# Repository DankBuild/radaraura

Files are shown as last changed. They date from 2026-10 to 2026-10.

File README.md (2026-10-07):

# RadarAura

A desk air-quality monitor: a 4.3" ESP32-P4 touch display plus a Sensirion SEN66
sensor in a 3D-printed case. It shows CO2, particulate matter (PM1/2.5/4/10), VOC
and NOx indices, temperature and humidity, with a one-hour CO2 trend and a plain
"what should I do" line.

**Build guide with wiring pictures: <https://radaraura.com/build/>**

<p>
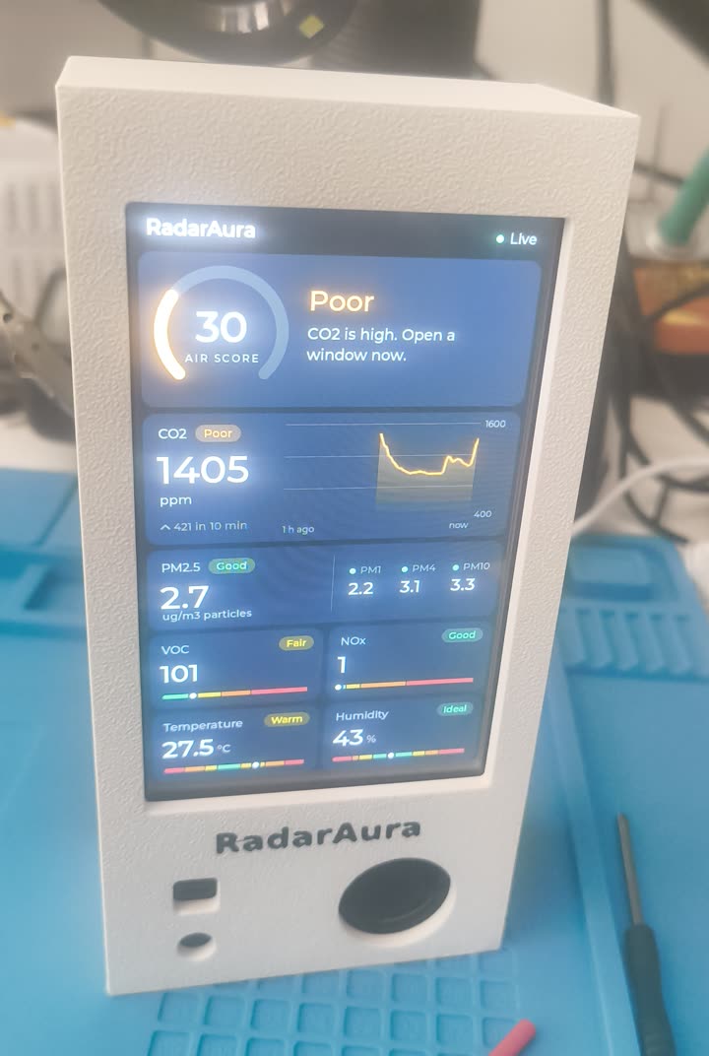
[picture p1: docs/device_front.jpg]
The finished RadarAura monitor in its white printed case, the screen showing an air score of 30 and CO2 at 1405 ppm
  
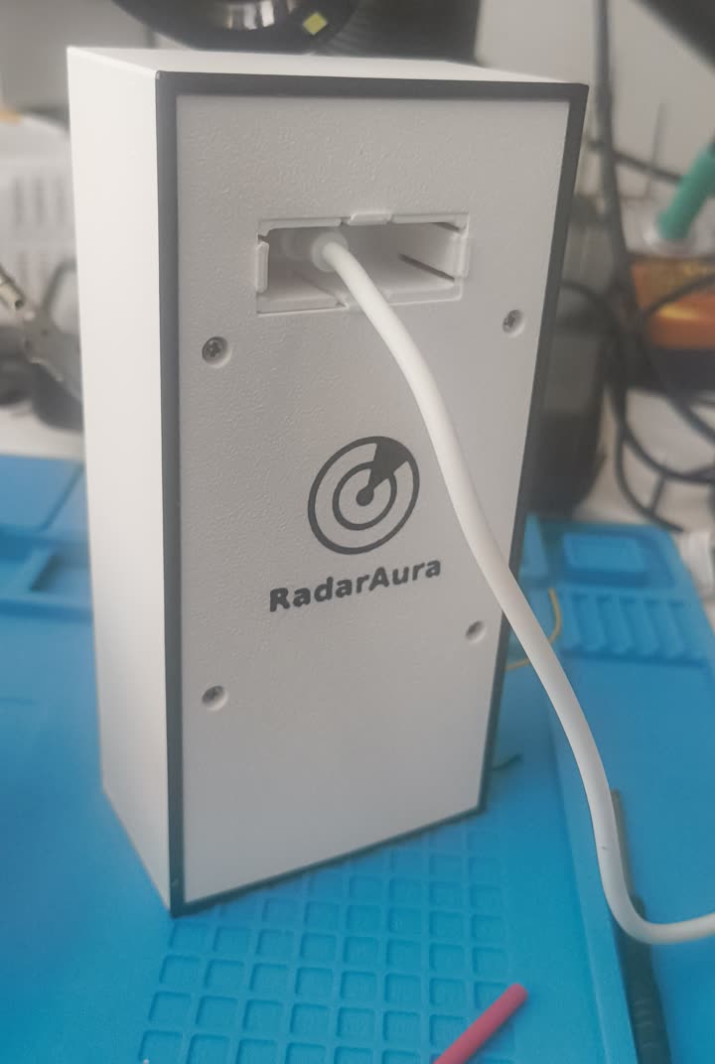
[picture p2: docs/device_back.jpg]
The back of the case with the radar mark, the RadarAura name and the USB-C cable
  
</p>

<p>
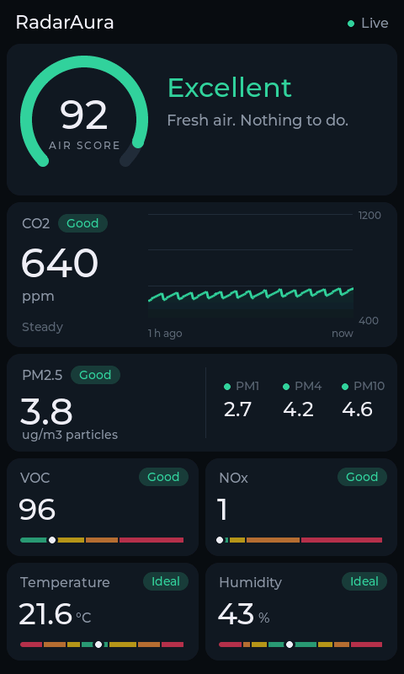
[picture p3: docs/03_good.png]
Dashboard with fresh air
  
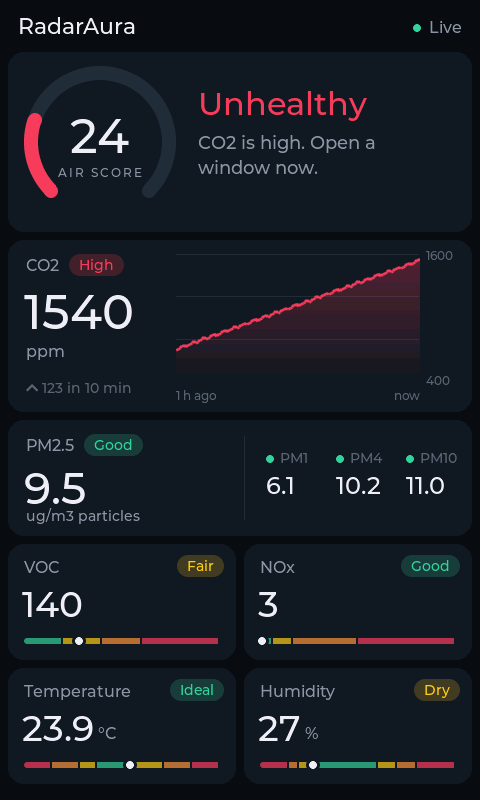
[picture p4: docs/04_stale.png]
Dashboard with high CO2
  
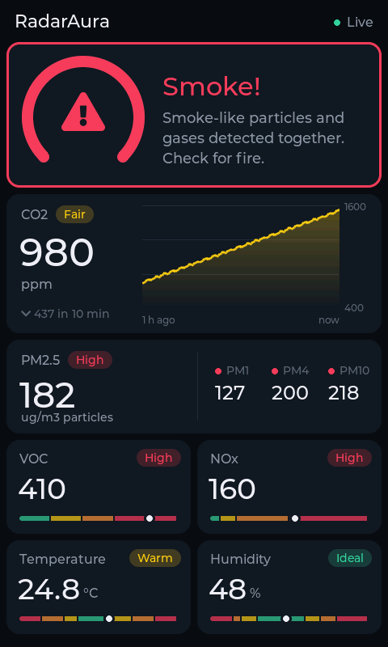
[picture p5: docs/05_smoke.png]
Smoke warning
  
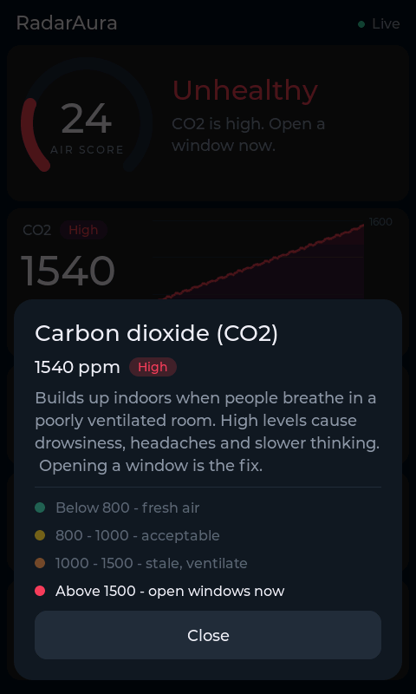
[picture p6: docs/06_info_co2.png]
CO2 explanation sheet
  
</p>

**Private by design:** no WiFi, no Bluetooth, no microphone. The board's ESP32-C6
radio chip is held in reset from the first instruction and no radio stack is
compiled in; the microphone is never switched on. Everything stays on the device.

## What you need

| # | Get this | Notes |
|---|---|---|
| 1 | **Guition JC4880P443C-I-W**, the bare board | ESP32-P4 with a 4.3" 480x800 touch screen (ST7701). Buy the version **without** the factory case (the one in its own plastic shell is usually listed with a "-Y" at the end); the RadarAura case is made for the bare board |
| 2 | **Sensirion SEN66** | PM, RH/T, VOC, NOx and CO2 in one module. Not the SEN63C, SEN65 or SEN68 |
| 3 | **SEN66 cable**: 6-pin, 1.25 mm pitch, JST GH type | Often sold separately, so check your order includes it. Wire colours don't matter |
| 4 | **A 3D printer, or someone to print for you** | Three parts in PETG, see [`case/`](case/README.md): one-colour or two-colour. A friend, makerspace, library or print service can print the STLs |

Tools: a soldering iron, heat-shrink, a USB-C cable with a USB power supply, and a
computer with ESP-IDF 5.3 to flash the firmware once. Optional: 4x M2 pan-head
screws (the case plugs tightly together and holds without them) and a second
filament colour for the name and radar mark. No resistors or other extra parts
are needed.

**Skill:** basic soldering. The four wires are soldered to the header pins. Female
jumper wires pushed onto the pins can work for a quick test, but they can slip or
lose contact when the case is closed ("Sensor offline"), and one slipping onto the
5 V pin next to pin 1 can damage the SEN66. Solder them for a device you keep.

**Wiring:** only 4 of the SEN66's 6 wires are needed (pins 5 and 6 repeat GND
and 3.3 V inside the sensor). They go to the board's 2x13 header, on the row
nearest the USB-C ports:

| SEN66 wire | Signal | Header pin |
|---|---|---|
| 1 (end of the plug farthest from the round outlet) | 3.3 V | 1 |
| 2 | GND | 5 |
| 3 | SDA (GPIO7) | 23 |
| 4 | SCL (GPIO8) | 25 |

Ignore the wire colours: these clip-in cables are not colour-coded consistently,
so red is not always 3.3 V and black is not always GND. Count by position from
wire 1.

Slide heat-shrink onto each wire before soldering, then shrink it over the joint:
no bare metal may touch a neighbouring pin (23 and 25 sit side by side, and the
5 V pins are next to pin 1).

The first two pins of the other row carry **5 V**: don't use them. I2C address
0x6B; the board already has the pull-ups. Pictures: <https://radaraura.com/build/#wiring>.

## Firmware

Requires [ESP-IDF](https://docs.espressif.com/projects/esp-idf/) 5.3 (tested with 5.3.5).

```sh
cd firmware
idf.py build
idf.py -p /dev/ttyACM0 flash monitor
```

RadarAura has no speaker: warnings, including the smoke warning, are shown on
the screen. The firmware still contains alert-sound code (settings at the top of
`firmware/main/main.c`, spoken alerts via `tools/generate_tts.py`), but the
standard build has nothing to play them on.

> The smoke warning is a convenience, **not a certified smoke detector**. Use a
> real smoke alarm for life safety.

### UI screenshots without hardware

`tools/ui_sim/build.sh` renders the dashboard on a PC to PNGs (run a firmware
build first; it reuses LVGL from `firmware/managed_components`).

## Case

See [`case/README.md`](case/README.md).

## Licence

Free to build and change for yourself, with the RadarAura name kept on the case
and the screen; selling requires permission. Everything is under the
[RadarAura Build Licence](LICENSE.md); the name rules are summed up in
[TRADEMARK.md](TRADEMARK.md).

Copyright (c) 2026 DankBuild.

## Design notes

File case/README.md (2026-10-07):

# Case

Printed parts, generated by `atmo4.py`. The STLs are already laid flat in print
orientation. Outside size about 72 x 149 x 42 mm. The SEN66 sits in its own
chamber below the screen with its air ports against the front openings.

## Choose how to print

The RadarAura name on the front and the radar mark on the back are part of the
case in both options (see [TRADEMARK.md](../TRADEMARK.md)).

### Option A: one colour (any printer)

Print these three parts. The name and the radar mark come out recessed 0.6 mm.

| File | Part | Lay it |
|---|---|---|
| `stl/v4_front_body.stl` | Front shell: screen window, sensor chamber in the chin, air openings, recessed name | screen face down |
| `stl/v4_rear_cover.stl` | Rear cover: screw posts, snap hooks, USB window, recessed radar mark | back down |
| `stl/v4_usb_insert.stl` | USB-C insert that clicks into the cover's window | floor down |

The recessed name is subtle in one colour. To make it readable, rub a little
acrylic paint (or a paint-marker line) into the letters and wipe the surface
clean before it dries.

### Option B: two colours (name and mark in a second colour)

The same three parts, plus two inlays that fill the recesses flush:

| File | Part |
|---|---|
| `stl/v4_front_body_name.stl` | The name, fills the recess in the front shell |
| `stl/v4_rear_cover_icon.stl` | The radar mark and name, fills the recess in the rear cover |

**Any printer:** everything above is in `stl/`, and STL files work in every
slicer (PrusaSlicer, Cura, OrcaSlicer, Bambu Studio and others).

**Multi-material printer (AMS, MMU, tool changer), from the STLs:**

1. Load the body and its inlay as **one object with two parts**:
   `v4_front_body.stl` + `v4_front_body_name.stl` for the front,
   `v4_rear_cover.stl` + `v4_rear_cover_icon.stl` for the back.
   - Bambu Studio, OrcaSlicer, PrusaSlicer: select both files in one import and
     answer **Yes** to "load as a single object with multiple parts".
   - Cura: load both, select both and use **Merge Models** (Ctrl+Alt+G).
2. Give the inlay part your second filament (extruder).
3. Slice. The colour only changes during the first three layers.

Bambu Studio / OrcaSlicer tip for a clean edge around the letters: under
Quality, set **Only one wall on first layer** on, **Wall generator** Arachne
and **Infill/wall overlap** 30%. With the defaults the slicer traces 2 walls
around every letter (a glossy outline) and leaves tiny pinholes where the fill
meets them.

**Single-nozzle printer (manual filament swap):** load only the body STL,
slice, and add a filament change at the layer above 0.6 mm (layer 4):
"Pause" in Bambu Studio and OrcaSlicer, "Add color change" (M600) in
PrusaSlicer, the "Pause at height" post-processing script in Cura. At the
pause, load the second colour, let it purge clean, print that one layer, then
switch back. The name shows in the second colour at the bottom of the recess,
plus a thin line around the edge.

## Optional: screws

The case plugs tightly together: the cover clicks in with snap hooks and holds
without screws. For extra security, 4 M2 pan-head screws go through the cover
into the board's standoffs. If you want them, print `stl/v4_screw_coupon.stl`
(one screw post) first to test the M2 fit against your board.

## Printing and assembly

- PETG, 0.2 mm layers, no supports.
- Press the cover in until the snap hooks click; it holds tightly on its own.
- Optional screws: 4 M2 pan-head, length depending on how deep your standoffs
  are threaded. The heads sink about 2 mm into recesses in the cover: if a
  screw stops before its head is down in the recess, it is bottoming out in the
  standoff, so use a shorter one (or cut it down).
- Push the USB insert into the cover's window from the outside until it clicks.

The full build, including the sensor wiring, is at
<https://radaraura.com/build/>.

## Optional: desk stand

`stl/stand_15deg.stl` and `stl/stand_25deg.stl` tilt the case back 15 or 25
degrees. The case drops in from above; the stand holds it by its sides, so the
air openings and the USB cable stay free. Prints flat on its base, no supports.
For another angle: `.venv/bin/python stand.py 20` writes `stl/stand_20deg.stl`.

## Changing the design

Every dimension you might tune is in the `PARAMS` block at the top of `atmo4.py`.

```sh
python3 -m venv .venv
.venv/bin/pip install trimesh manifold3d shapely numpy
.venv/bin/python atmo4.py      # writes stl/
```

The script prints the size, watertightness and body count of each part. Both
should report `watertight=True` and `bodies=1`.

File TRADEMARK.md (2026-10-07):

# The RadarAura name

"RadarAura" and the radar mark identify the RadarAura air monitor by DankBuild.
The licence ([LICENSE.md](LICENSE.md)) covers the files; this page sums up the
rules for the name.

- **Every build keeps the name.** The name on the front of the case, the radar
  mark with the name on the back, and the RadarAura title on the screen stay on
  every device, also one built only for yourself (licence section 2).
- **Modified versions you share** keep the name and say they are modified:
  "RadarAura, modified by \<your name\>". They must not suggest that DankBuild
  made or approved the changes.
- **Selling** anything under the RadarAura name requires written permission
  from DankBuild.
- The name is not licensed for anything else: other products, services,
  domains or accounts.

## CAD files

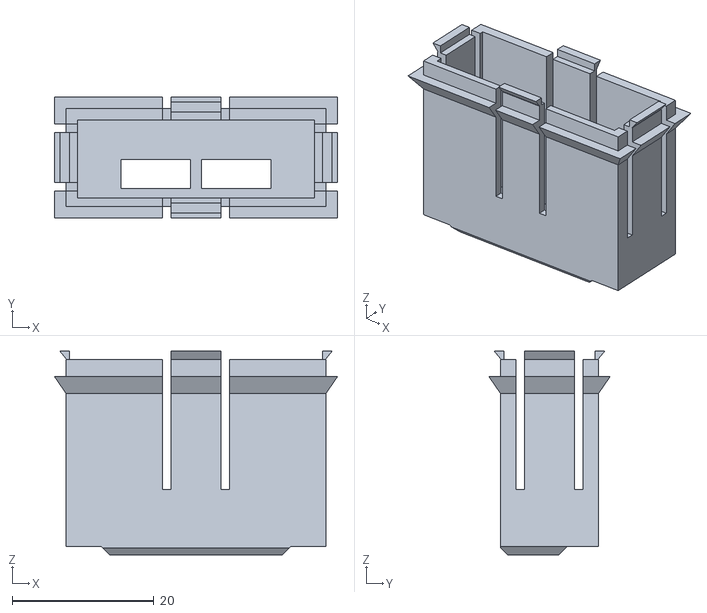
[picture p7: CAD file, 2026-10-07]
case/stl/v4_usb_insert.stl
40.0 x 17.1 x 28.8

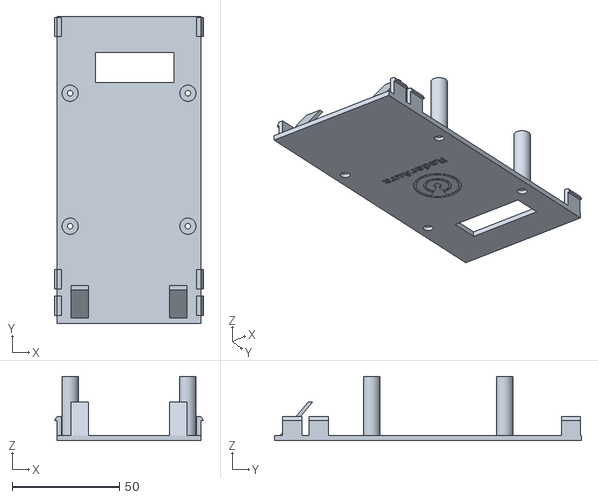
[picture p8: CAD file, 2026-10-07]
case/stl/v4_rear_cover.stl
69.6 x 143.5 x 30.1

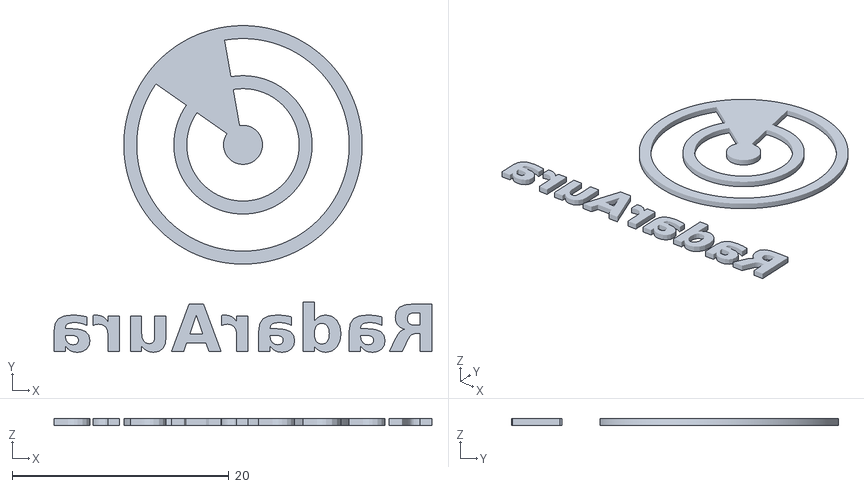
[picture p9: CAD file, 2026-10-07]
case/stl/v4_rear_cover_icon.stl
34.9 x 30.1 x 0.6

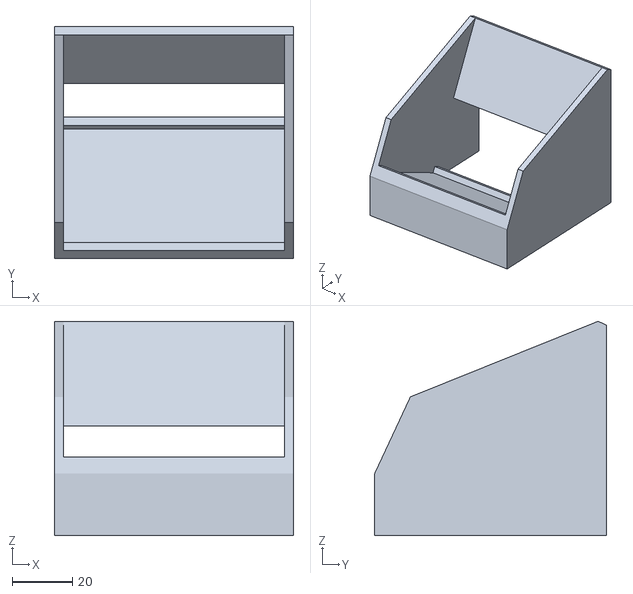
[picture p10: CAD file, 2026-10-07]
case/stl/stand_25deg.stl
79.2 x 76.8 x 71.1

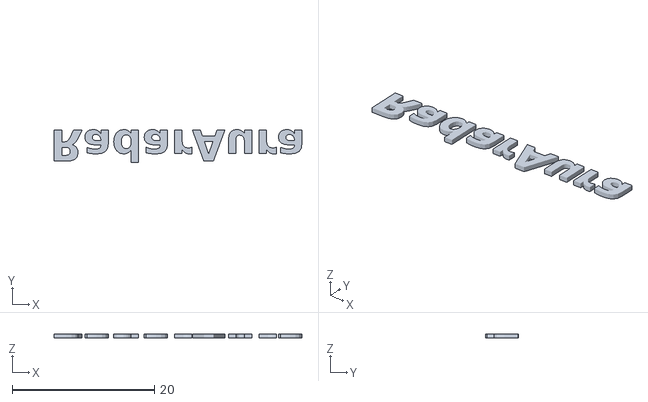
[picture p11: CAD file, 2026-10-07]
case/stl/v4_front_body_name.stl
34.9 x 4.64 x 0.6

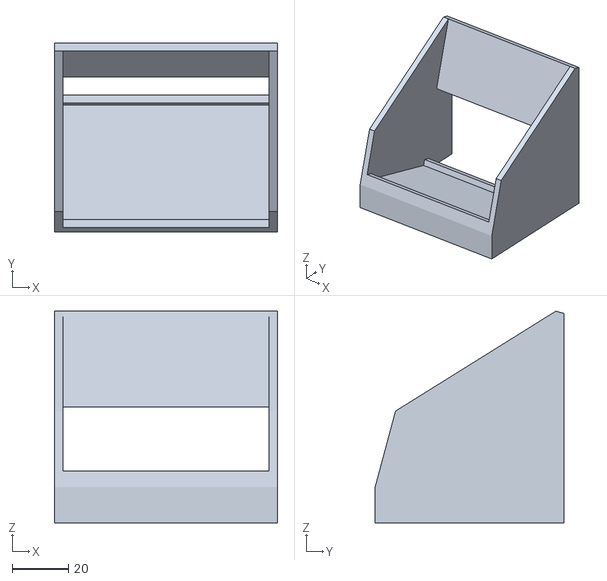
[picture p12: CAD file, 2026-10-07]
case/stl/stand_15deg.stl
79.2 x 67.1 x 75.2

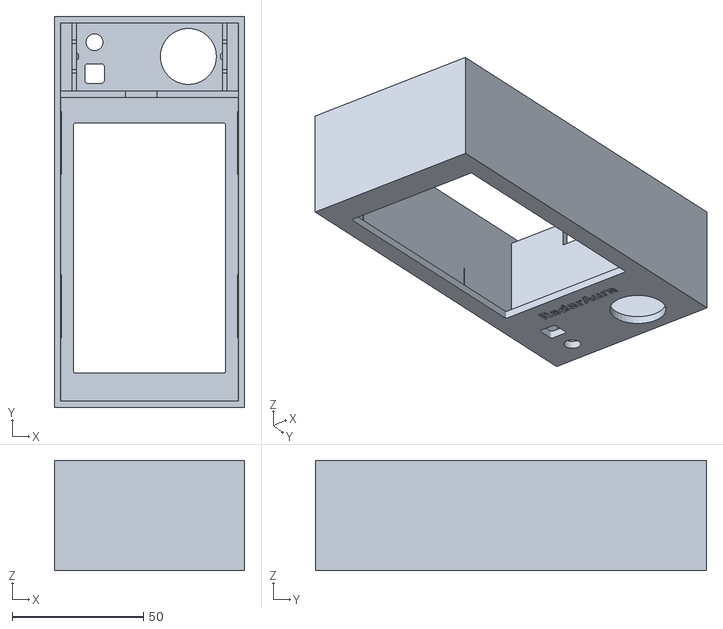
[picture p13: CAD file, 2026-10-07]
case/stl/v4_front_body.stl
72.4 x 148.7 x 42.0

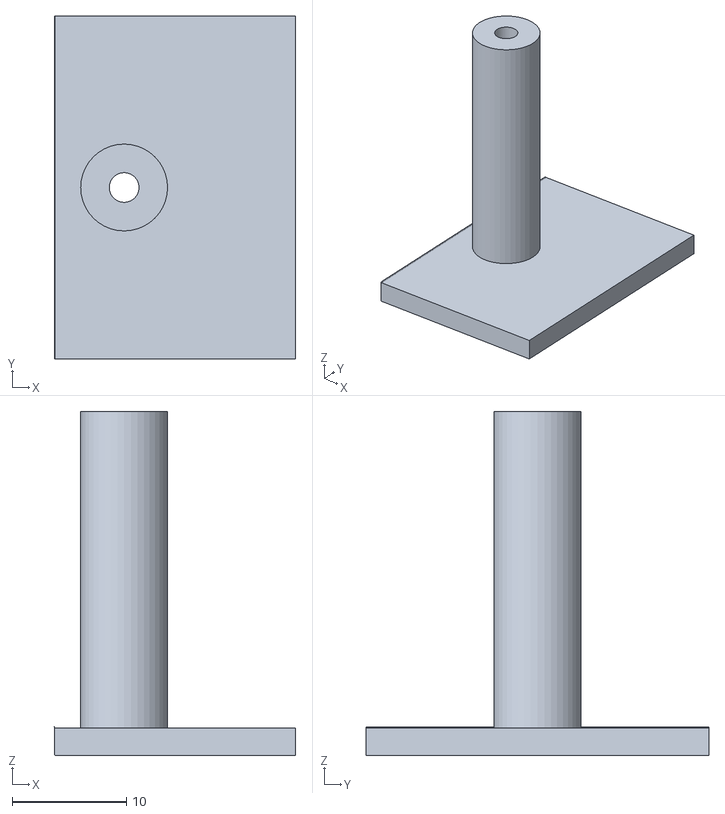
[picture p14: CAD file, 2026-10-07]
case/stl/v4_screw_coupon.stl
21.1 x 30.0 x 30.1

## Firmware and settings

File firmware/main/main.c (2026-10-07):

/**
 * Copyright (c) 2026 DankBuild - RadarAura (https://github.com/DankBuild/radaraura)
 * Licensed under the RadarAura Build Licence 1.0 - see LICENSE.md
 *
 * SEN66 Air Quality Monitor - sensor, alarms and audio.
 * The 480x800 dashboard itself lives in ui.c.
 */

#include "freertos/FreeRTOS.h"
#include "freertos/task.h"
#include "driver/i2c_master.h"
#include "esp_log.h"
#include "esp_timer.h"
#include "esp_spiffs.h"
#include "bsp/esp-bsp.h"
#include "bsp/display.h"
#include "bsp/esp32_p4_function_ev_board.h"
#include "bsp_board_extra.h"
#include "lvgl.h"
#include "ui.h"
#include "driver/gpio.h"
#include <math.h>
#include <stdio.h>
#include <string.h>
#include <stdlib.h>

static const char *TAG = "airquality";

#define I2C_SDA_PIN           GPIO_NUM_7
#define I2C_SCL_PIN           GPIO_NUM_8
#define SEN66_I2C_ADDR        0x6B
#define SEN66_CMD_RESET       0xD304
#define SEN66_CMD_START       0x0021
#define SEN66_CMD_READ_VALUES 0x0300

// Alarm cooldowns: how long before the same alert can re-trigger
#define ALARM_COOLDOWN_US      (5LL * 60 * 1000 * 1000)  // 5 minutes - normal alerts
#define FIRE_COOLDOWN_US       (1LL * 60 * 1000 * 1000)  // 1 minute - fire alert (more urgent)
#define FIRE_REPEAT_COUNT      3                          // Fire alarm plays this many times per trigger
#define BEEP_SAMPLE_RATE       44100
#define BEEP_FREQ_HZ           880   // A5 - clearly audible
#define BEEP_DURATION_MS       400

// Fire/smoke alert thresholds (NOT user-adjustable - safety-critical, research-based).
// All three must be exceeded simultaneously for the fire alarm to trigger.
//   PM2.5 > 50 ug/m3  : sustained smoke particles (above EPA "unhealthy" threshold)
//   VOC index > 300   : strong combustion VOC signal
//   NOx index > 100   : combustion NOx signal (well above ambient ~50)
#define FIRE_PM25_THRESHOLD   50.0f
#define FIRE_VOC_THRESHOLD    300.0f
#define FIRE_NOX_THRESHOLD    100.0f

// === Alert configuration ===
// There is no on-device settings menu: edit these and rebuild. Sound needs a
// speaker on the board's speaker connector; without one everything is silent.
#define ALERT_VOLUME          70   // 0-100
#define FIRE_ALERT_ENABLED    1    // smoke/fire alarm (PM2.5 + VOC + NOx all high at once)
#define METRIC_ALERTS_ENABLED 0    // beep when a single metric passes metric_thresholds[]
#define ALERT_VOICE_ENABLED   1    // spoken message after the beep (TTS MP3s in SPIFFS/SD)
#define ALERT_VOICE_INDEX     0    // 0=Calm 1=Lovely 2=Kind 3=Graceful (voice_dirs below)

static i2c_master_bus_handle_t i2c_bus = NULL;
static i2c_master_dev_handle_t sen66_dev = NULL;

// Metric indices used in arrays
enum {
    M_CO2 = 0,
    M_PM1,
    M_PM25,
    M_PM4,
    M_PM10,
    M_VOC,
    M_NOX,
    M_TEMP_HI,
    M_HUM_HI,
    M_COUNT
};

static const char *metric_names[M_COUNT] = {
    "CO2 ppm", "PM1.0 ug/m3", "PM2.5 ug/m3", "PM4.0 ug/m3", "PM10 ug/m3",
    "VOC Index", "NOx Index", "Temp high (C)", "Humidity high (%)"
};
// Filenames (without path/extension) for TTS audio playback
static const char *metric_tts_files[M_COUNT] = {
    "co2", "pm1", "pm25", "pm4", "pm10", "voc", "nox", "temp", "humid"
};
// Per-metric alert thresholds (only used when METRIC_ALERTS_ENABLED)
static const float metric_thresholds[M_COUNT] = {
    1500, 25, 55, 75, 150, 300, 150, 35, 85
};

// Voice options - match generate_tts.py VOICES order. Subdirectory name in /spiffs or /sdcard/alerts/
#define VOICE_COUNT 4
static const char *voice_dirs[VOICE_COUNT] = { "voice1", "voice2", "voice3", "voice4" };

static bool audio_ready = false;
static bool sdcard_ready = false;
static bool spiffs_ready = false;
#define SDCARD_MOUNT_POINT  "/sdcard"
#define SPIFFS_MOUNT_POINT  "/spiffs"
// We try SPIFFS first (firmware-bundled audio), then SD card as fallback
#define TTS_EXT             ".mp3"

// Last alarm timestamp per metric + fire (to enforce cooldown)
static int64_t last_alarm_us[M_COUNT + 1] = {0};  // last is fire

// Generate and play a sine wave beep on the speaker
static void play_beep(int freq_hz, int duration_ms)
{
    if (!audio_ready) return;

    size_t samples = (BEEP_SAMPLE_RATE * duration_ms) / 1000;
    int16_t *buf = malloc(samples * 2 * sizeof(int16_t));  // stereo
    if (!buf) return;

    float omega = 2.0f * (float)M_PI * freq_hz / BEEP_SAMPLE_RATE;
    int fade = BEEP_SAMPLE_RATE / 100;  // 10ms fade in/out to avoid pops
    for (size_t i = 0; i < samples; i++) {
        float env = 1.0f;
        if ((int)i < fade) env = (float)i / fade;
        else if ((int)i > (int)samples - fade) env = (float)(samples - i) / fade;
        int16_t s = (int16_t)(sinf(omega * i) * 28000 * env);
        buf[i*2]     = s;
        buf[i*2 + 1] = s;
    }

    size_t bytes_written = 0;
    bsp_extra_i2s_write(buf, samples * 2 * sizeof(int16_t), &bytes_written, 5000);
    free(buf);
}

// Try to play a TTS file. Looks in SPIFSS (firmware-bundled) first,
// then SD card (/sdcard/alerts/). Returns true if started.
static bool try_play_tts(const char *name)
{
    if (!ALERT_VOICE_ENABLED) return false;
    char path[128];

    // 1) SPIFFS bundled (preferred) - files were packed at build time
    if (spiffs_ready) {
        snprintf(path, sizeof(path), "%s/%s/%s%s",
                 SPIFFS_MOUNT_POINT, voice_dirs[ALERT_VOICE_INDEX], name, TTS_EXT);
        FILE *f = fopen(path, "r");
        if (f) {
            fclose(f);
            if (bsp_extra_player_play_file(path) == ESP_OK) {
                ESP_LOGI(TAG, "Playing TTS (spiffs): %s", path);
                return true;
            }
        }
    }

    // 2) SD card fallback (/sdcard/alerts/voiceN/...)
    if (sdcard_ready) {
        snprintf(path, sizeof(path), "%s/alerts/%s/%s%s",
                 SDCARD_MOUNT_POINT, voice_dirs[ALERT_VOICE_INDEX], name, TTS_EXT);
        FILE *f = fopen(path, "r");
        if (f) {
            fclose(f);
            if (bsp_extra_player_play_file(path) == ESP_OK) {
                ESP_LOGI(TAG, "Playing TTS (sd): %s", path);
                return true;
            }
        }
    }

    ESP_LOGW(TAG, "TTS file not found for '%s'", name);
    return false;
}

// Async task: play attention beep, then voice file (if available)
static void play_metric_alert_task(void *arg)
{
    int idx = (int)(intptr_t)arg;
    play_beep(BEEP_FREQ_HZ, 250);
    vTaskDelay(pdMS_TO_TICKS(80));
    play_beep(BEEP_FREQ_HZ + 200, 250);
    vTaskDelay(pdMS_TO_TICKS(300));
    if (idx >= 0 && idx < M_COUNT) {
        try_play_tts(metric_tts_files[idx]);
    }
    vTaskDelete(NULL);
}

static void play_fire_alert_task(void *arg)
{
    // Repeat the urgent pattern several times - fire is safety-critical
    for (int rep = 0; rep < FIRE_REPEAT_COUNT; rep++) {
        // Urgent rapid beeps
        for (int i = 0; i < 4; i++) {
            play_beep(1200, 150);
            vTaskDelay(pdMS_TO_TICKS(60));
        }
        vTaskDelay(pdMS_TO_TICKS(200));
        try_play_tts("fire");
        vTaskDelay(pdMS_TO_TICKS(800));  // pause between repeats
    }
    vTaskDelete(NULL);
}

static void trigger_metric_alert(int metric_idx)
{
    if (!audio_ready) return;
    xTaskCreate(play_metric_alert_task, "alert", 4096,
                (void*)(intptr_t)metric_idx, 4, NULL);
}

static void maybe_alarm_metric(int metric_idx, float value)
{
    if (!METRIC_ALERTS_ENABLED) return;
    if (value < metric_thresholds[metric_idx]) return;
    int64_t now = esp_timer_get_time();
    if (now - last_alarm_us[metric_idx] < ALARM_COOLDOWN_US) return;
    last_alarm_us[metric_idx] = now;
    ESP_LOGW(TAG, "ALARM: %s exceeded (%.1f >= %.1f)",
             metric_names[metric_idx], value, metric_thresholds[metric_idx]);
    trigger_metric_alert(metric_idx);
}

// Called while the combined fire condition holds (see handle_sample)
static void maybe_fire_alarm(float pm25, float voc, float nox)
{
    int64_t now = esp_timer_get_time();
    // Fire uses its own shorter cooldown - re-warn aggressively while smoke persists
    if (now - last_alarm_us[M_COUNT] < FIRE_COOLDOWN_US) return;
    last_alarm_us[M_COUNT] = now;
    ESP_LOGE(TAG, "FIRE ALARM: PM2.5=%.1f VOC=%.0f NOx=%.0f", pm25, voc, nox);
    if (!audio_ready) return;
    xTaskCreate(play_fire_alert_task, "fire_alert", 4096, NULL, 5, NULL);
}

static uint8_t sensirion_crc8(const uint8_t *data, size_t len)
{
    uint8_t crc = 0xFF;
    for (size_t i = 0; i < len; i++) {
        crc ^= data[i];
        for (int j = 0; j < 8; j++) {
            crc = (crc & 0x80) ? (crc << 1) ^ 0x31 : (crc << 1);
        }
    }
    return crc;
}

static esp_err_t sen66_send_cmd(uint16_t cmd)
{
    uint8_t buf[2] = {cmd >> 8, cmd & 0xFF};
    return i2c_master_transmit(sen66_dev, buf, 2, 1000);
}

static esp_err_t sen66_read_with_crc(uint8_t *out, size_t len)
{
    size_t raw_len = (len / 2) * 3;
    uint8_t *raw = malloc(raw_len);
    if (!raw) return ESP_ERR_NO_MEM;
    esp_err_t ret = i2c_master_receive(sen66_dev, raw, raw_len, 1000);
    if (ret == ESP_OK) {
        for (size_t i = 0, j = 0; i < raw_len; i += 3, j += 2) {
            if (sensirion_crc8(&raw[i], 2) != raw[i + 2]) {
                ESP_LOGW(TAG, "CRC error - frame dropped");
                ret = ESP_ERR_INVALID_CRC;
            }
            out[j] = raw[i];
            out[j + 1] = raw[i + 1];
        }
    }
    free(raw);
    return ret;
}

// SEN66 "unknown" markers (datasheet: returned until a value is available,
// e.g. CO2 during the first seconds and VOC/NOx during warm-up)
#define SEN66_U16_UNKNOWN 0xFFFF
#define SEN66_I16_UNKNOWN 0x7FFF

// Consecutive failed reads before the dashboard shows "Sensor offline"
#define SENSOR_OFFLINE_AFTER 5

static void handle_sample(air_sample_t *s)
{
    // Combined fire/smoke condition: PM2.5 + VOC + NOx all spike together
    s->fire = FIRE_ALERT_ENABLED && s->pm_ok && s->voc_ok && s->nox_ok &&
              s->pm25 >= FIRE_PM25_THRESHOLD &&
              s->voc  >= FIRE_VOC_THRESHOLD &&
              s->nox  >= FIRE_NOX_THRESHOLD;

    ui_update(s);

    // Per-metric alarms (each with own threshold + cooldown) - only on valid data
    if (s->co2_ok) maybe_alarm_metric(M_CO2, (float)s->co2);
    if (s->pm_ok) {
        maybe_alarm_metric(M_PM1,  s->pm1);
        maybe_alarm_metric(M_PM25, s->pm25);
        maybe_alarm_metric(M_PM4,  s->pm4);
        maybe_alarm_metric(M_PM10, s->pm10);
    }
    if (s->voc_ok) maybe_alarm_metric(M_VOC, s->voc);
    if (s->nox_ok) maybe_alarm_metric(M_NOX, s->nox);
    if (s->rht_ok) {
        maybe_alarm_metric(M_TEMP_HI, s->temp);
        maybe_alarm_metric(M_HUM_HI,  s->humid);
    }
    if (s->fire) maybe_fire_alarm(s->pm25, s->voc, s->nox);
}

static void sensor_task(void *arg)
{
    ESP_LOGI(TAG, "Starting sensor task...");

    // Reset sensor
    sen66_send_cmd(SEN66_CMD_RESET);
    vTaskDelay(pdMS_TO_TICKS(1500));  // SEN66 needs time after reset

    // Start measurement
    sen66_send_cmd(SEN66_CMD_START);
    vTaskDelay(pdMS_TO_TICKS(50));

    ESP_LOGI(TAG, "Sensor started, reading data...");

    int failures = 0;
    while (1) {
        uint8_t data[18];
        esp_err_t ret = sen66_send_cmd(SEN66_CMD_READ_VALUES);
        if (ret == ESP_OK) {
            vTaskDelay(pdMS_TO_TICKS(20));
            ret = sen66_read_with_crc(data, 18);
        }

        if (ret == ESP_OK) {
            failures = 0;
            uint16_t r_pm1  = (data[0] << 8) | data[1];
            uint16_t r_pm25 = (data[2] << 8) | data[3];
            uint16_t r_pm4  = (data[4] << 8) | data[5];
            uint16_t r_pm10 = (data[6] << 8) | data[7];
            int16_t  r_hum  = (int16_t)((data[8] << 8) | data[9]);
            int16_t  r_temp = (int16_t)((data[10] << 8) | data[11]);
            int16_t  r_voc  = (int16_t)((data[12] << 8) | data[13]);
            int16_t  r_nox  = (int16_t)((data[14] << 8) | data[15]);
            uint16_t r_co2  = (data[16] << 8) | data[17];

            air_sample_t s = {
                .pm_ok  = r_pm1 != SEN66_U16_UNKNOWN && r_pm25 != SEN66_U16_UNKNOWN &&
                          r_pm4 != SEN66_U16_UNKNOWN && r_pm10 != SEN66_U16_UNKNOWN,
                .rht_ok = r_hum != SEN66_I16_UNKNOWN && r_temp != SEN66_I16_UNKNOWN,
                // Index range is 1..500; the SEN66 reports 0 until its
                // VOC/NOx algorithms have warmed up (~1-3 min after start)
                .voc_ok = r_voc != SEN66_I16_UNKNOWN && r_voc > 0,
                .nox_ok = r_nox != SEN66_I16_UNKNOWN && r_nox > 0,
                .co2_ok = r_co2 != SEN66_U16_UNKNOWN,
                .pm1 = r_pm1 / 10.0f, .pm25 = r_pm25 / 10.0f,
                .pm4 = r_pm4 / 10.0f, .pm10 = r_pm10 / 10.0f,
                .humid = r_hum / 100.0f, .temp = r_temp / 200.0f,
                .voc = r_voc / 10.0f, .nox = r_nox / 10.0f,
                .co2 = r_co2,
            };

            ESP_LOGI(TAG, "CO2:%d PM1:%.1f PM2.5:%.1f PM4:%.1f PM10:%.1f T:%.1f H:%.0f VOC:%.0f NOx:%.0f",
                     s.co2, s.pm1, s.pm25, s.pm4, s.pm10, s.temp, s.humid, s.voc, s.nox);

            bsp_display_lock(0);
            handle_sample(&s);
            bsp_display_unlock();
        } else if (++failures == SENSOR_OFFLINE_AFTER) {
            ESP_LOGE(TAG, "SEN66 not responding (%s)", esp_err_to_name(ret));
            bsp_display_lock(0);
            ui_set_sensor_state(UI_SENSOR_OFFLINE);
            bsp_display_unlock();
        }

        vTaskDelay(pdMS_TO_TICKS(1000));
    }
}

/* Radio kill-switch: the ESP32-C6 co-processor is this module's ONLY radio
 * (the P4 has none in silicon). Its enable/reset line is wired to P4 GPIO54
 * (active-high to run; SDIO on GPIO14-19 — per JC-ESP32P4-M3 documentation).
 * Driving GPIO54 LOW from first boot holds the C6 permanently in reset: it
 * never executes a single instruction — no WiFi, no BLE, no radio firmware
 * running. Combined with this application containing no radio stack at all
 * (no esp_wifi_remote / esp_hosted components are compiled in), the product
 * has no functioning radio. Do NOT change this in a production build. */
#define C6_RADIO_EN_GPIO 54

static void radio_hold_in_reset(void)
{
    const gpio_config_t cfg = {
        .pin_bit_mask  = 1ULL << C6_RADIO_EN_GPIO,
        .mode          = GPIO_MODE_OUTPUT,
        .pull_up_en    = GPIO_PULLUP_DISABLE,
        .pull_down_en  = GPIO_PULLDOWN_ENABLE,
        .intr_type     = GPIO_INTR_DISABLE,
    };
    gpio_config(&cfg);
    gpio_set_level(C6_RADIO_EN_GPIO, 0);   /* EN low = C6 held in reset */
    gpio_hold_en(C6_RADIO_EN_GPIO);        /* latch the level against glitches */
    ESP_LOGI("radio", "ESP32-C6 held in permanent reset (GPIO%d low) — no radio", C6_RADIO_EN_GPIO);
}

void app_main(void)
{
    radio_hold_in_reset();   /* first thing, before anything else runs */

    ESP_LOGI(TAG, "Starting Air Quality Monitor...");

    bsp_display_cfg_t cfg = {
        .lvgl_port_cfg = ESP_LVGL_PORT_INIT_CONFIG(),
        .buffer_size = BSP_LCD_DRAW_BUFF_SIZE,
        .double_buffer = BSP_LCD_DRAW_BUFF_DOUBLE,
        .flags = {
            .buff_dma = true,
            .buff_spiram = false,
            .sw_rotate = false,
        }
    };
    bsp_display_start_with_config(&cfg);
    bsp_display_backlight_on();

    // Mount SPIFFS (firmware-bundled TTS audio files in 'storage' partition)
    {
        esp_vfs_spiffs_conf_t conf = {
            .base_path = SPIFFS_MOUNT_POINT,
            .partition_label = "storage",
            .max_files = 5,
            .format_if_mount_failed = false,
        };
        esp_err_t r = esp_vfs_spiffs_register(&conf);
        if (r == ESP_OK) {
            spiffs_ready = true;
            size_t total = 0, used = 0;
            esp_spiffs_info("storage", &total, &used);
            ESP_LOGI(TAG, "SPIFFS mounted at %s (%u/%u bytes used)",
                     SPIFFS_MOUNT_POINT, (unsigned)used, (unsigned)total);
        } else {
            ESP_LOGW(TAG, "SPIFFS mount failed: %s", esp_err_to_name(r));
        }
    }

    // Mount SD card (optional fallback)
    if (bsp_sdcard_mount() == ESP_OK) {
        sdcard_ready = true;
        ESP_LOGI(TAG, "SD card mounted at %s", SDCARD_MOUNT_POINT);
    } else {
        ESP_LOGW(TAG, "SD card not mounted");
    }

    // Initialize audio codec (ES8311) and apply saved volume/mute
    if (bsp_extra_codec_init() == ESP_OK) {
        bsp_extra_codec_set_fs(BEEP_SAMPLE_RATE, 16, I2S_SLOT_MODE_STEREO);
        int set = ALERT_VOLUME;
        bsp_extra_codec_volume_set(ALERT_VOLUME, &set);
        bsp_extra_codec_mute_set(false);
        // Initialize audio player ONLY if we have TTS files (SPIFFS or SD).
        // Otherwise the player claims the I2S channel and breaks our direct beeps.
        if (spiffs_ready || sdcard_ready) {
            bsp_extra_player_init();
            ESP_LOGI(TAG, "Audio player initialized for TTS playback");
        }
        audio_ready = true;
        ESP_LOGI(TAG, "Audio codec ready");
    } else {
        ESP_LOGW(TAG, "Audio codec init failed - alarms disabled");
    }
    
    bsp_display_lock(0);
    ui_create();
    bsp_display_unlock();
    
    ESP_LOGI(TAG, "Display ready, UI should be visible now");
    
    // Give LVGL time to render the UI
    vTaskDelay(pdMS_TO_TICKS(500));
    
    // Get the existing I2C bus from BSP (shared with touch)
    i2c_bus = bsp_i2c_get_handle();
    
    i2c_device_config_t dev_cfg = {
        .dev_addr_length = I2C_ADDR_BIT_LEN_7,
        .device_address = SEN66_I2C_ADDR,
        .scl_speed_hz = 100000,
    };
    ESP_ERROR_CHECK(i2c_master_bus_add_device(i2c_bus, &dev_cfg, &sen66_dev));
    
    ESP_LOGI(TAG, "I2C ready");
    xTaskCreate(sensor_task, "sensor", 4096, NULL, 5, NULL);
}

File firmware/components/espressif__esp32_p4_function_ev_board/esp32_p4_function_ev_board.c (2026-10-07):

/*
 * SPDX-FileCopyrightText: 2024 Espressif Systems (Shanghai) CO LTD
 *
 * SPDX-License-Identifier: Apache-2.0
 */

#include "sdkconfig.h"
#include "driver/gpio.h"
#include "driver/ledc.h"
#include "esp_err.h"
#include "esp_log.h"
#include "esp_check.h"
#include "esp_spiffs.h"
#include "esp_lcd_panel_ops.h"
#include "esp_lcd_mipi_dsi.h"
#include "esp_ldo_regulator.h"
#include "esp_vfs_fat.h"
#include "usb/usb_host.h"
#include "sd_pwr_ctrl_by_on_chip_ldo.h"


#if CONFIG_BSP_LCD_TYPE_1024_600
#include "esp_lcd_ek79007.h"
#include "esp_lcd_st7701.h"
#else
#include "esp_lcd_ili9881c.h"
#endif

#include "bsp/esp32_p4_function_ev_board.h"
#include "bsp/display.h"
#include "bsp/touch.h"
#include "esp_lcd_touch_gt911.h"
#include "bsp_err_check.h"
#include "esp_codec_dev_defaults.h"
#include "lvgl.h"

static const char *TAG = "ESP32_P4_EV";

#if (BSP_CONFIG_NO_GRAPHIC_LIB == 0)
static lv_indev_t *disp_indev = NULL;
#endif // (BSP_CONFIG_NO_GRAPHIC_LIB == 0)

sdmmc_card_t *bsp_sdcard = NULL;    // Global uSD card handler
static bool i2c_initialized = false;
static TaskHandle_t usb_host_task;  // USB Host Library task
#if (ESP_IDF_VERSION >= ESP_IDF_VERSION_VAL(5, 3, 0))
static i2c_master_bus_handle_t i2c_handle = NULL;  // I2C Handle
#endif
static i2s_chan_handle_t i2s_tx_chan = NULL;
static i2s_chan_handle_t i2s_rx_chan = NULL;
static const audio_codec_data_if_t *i2s_data_if = NULL;  /* Codec data interface */

/* Can be used for `i2s_std_gpio_config_t` and/or `i2s_std_config_t` initialization */
#define BSP_I2S_GPIO_CFG       \
    {                          \
        .mclk = BSP_I2S_MCLK,  \
        .bclk = BSP_I2S_SCLK,  \
        .ws = BSP_I2S_LCLK,    \
        .dout = BSP_I2S_DOUT,  \
        .din = BSP_I2S_DSIN,   \
        .invert_flags = {      \
            .mclk_inv = false, \
            .bclk_inv = false, \
            .ws_inv = false,   \
        },                     \
    }

/* This configuration is used by default in `bsp_extra_audio_init()` */
#define BSP_I2S_DUPLEX_MONO_CFG(_sample_rate)                                                         \
    {                                                                                                 \
        .clk_cfg = I2S_STD_CLK_DEFAULT_CONFIG(_sample_rate),                                          \
        .slot_cfg = I2S_STD_PHILIP_SLOT_DEFAULT_CONFIG(I2S_DATA_BIT_WIDTH_16BIT, I2S_SLOT_MODE_STEREO), \
        .gpio_cfg = BSP_I2S_GPIO_CFG,                                                                 \
    }

esp_err_t bsp_i2c_init(void)
{
    /* I2C was initialized before */
    if (i2c_initialized) {
        return ESP_OK;
    }

    i2c_master_bus_config_t i2c_bus_conf = {
        .clk_source = I2C_CLK_SRC_DEFAULT,
        .sda_io_num = BSP_I2C_SDA,
        .scl_io_num = BSP_I2C_SCL,
        .i2c_port = BSP_I2C_NUM,
    };
    BSP_ERROR_CHECK_RETURN_ERR(i2c_new_master_bus(&i2c_bus_conf, &i2c_handle));

    i2c_initialized = true;

    return ESP_OK;
}

esp_err_t bsp_i2c_deinit(void)
{
    BSP_ERROR_CHECK_RETURN_ERR(i2c_del_master_bus(i2c_handle));
    i2c_initialized = false;
    return ESP_OK;
}

i2c_master_bus_handle_t bsp_i2c_get_handle(void)
{
    return i2c_handle;
}

esp_err_t bsp_sdcard_mount(void)
{
    const esp_vfs_fat_sdmmc_mount_config_t mount_config = {
#ifdef CONFIG_BSP_SD_FORMAT_ON_MOUNT_FAIL
        .format_if_mount_failed = true,
#else
        .format_if_mount_failed = false,
#endif
        .max_files = 5,
        .allocation_unit_size = 64 * 1024
    };

    sdmmc_host_t host = SDMMC_HOST_DEFAULT();
    host.slot = SDMMC_HOST_SLOT_0;
    host.max_freq_khz = SDMMC_FREQ_HIGHSPEED;

    sd_pwr_ctrl_ldo_config_t ldo_config = {
        .ldo_chan_id = 4,
    };
    sd_pwr_ctrl_handle_t pwr_ctrl_handle = NULL;
    esp_err_t ret = sd_pwr_ctrl_new_on_chip_ldo(&ldo_config, &pwr_ctrl_handle);
    if (ret != ESP_OK) {
        ESP_LOGE(TAG, "Failed to create a new on-chip LDO power control driver");
        return ret;
    }
    host.pwr_ctrl_handle = pwr_ctrl_handle;

    const sdmmc_slot_config_t slot_config = {
        /* SD card is connected to Slot 0 pins. Slot 0 uses IO MUX, so not specifying the pins here */
        .cd = SDMMC_SLOT_NO_CD,
        .wp = SDMMC_SLOT_NO_WP,
        .width = 4,
        .flags = 0,
    };

    return esp_vfs_fat_sdmmc_mount(BSP_SD_MOUNT_POINT, &host, &slot_config, &mount_config, &bsp_sdcard);
}

esp_err_t bsp_sdcard_unmount(void)
{
    return esp_vfs_fat_sdcard_unmount(BSP_SD_MOUNT_POINT, bsp_sdcard);
}
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

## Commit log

2026-10-07 RadarAura: desk air monitor - firmware, case and build files
    ESP32-P4 4.3" screen + Sensirion SEN66 in a 3D-printed case. No WiFi,
    Bluetooth or microphone. Build guide: https://radaraura.com/build/
    Released under the RadarAura Build Licence 1.0 (LICENSE.md).
    [partitions.csv, stand_15deg.stl, stand_25deg.stl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]
2026-10-07 README: clear "What you need" list (bare board, SEN66, cable, printer)
2026-10-07 README: basic soldering is needed; push-on jumpers are risky
2026-10-07 README: heat-shrink every solder joint
2026-10-07 README: cable colours vary, count by position
